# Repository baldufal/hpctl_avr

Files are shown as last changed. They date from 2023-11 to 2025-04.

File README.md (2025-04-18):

# HPCTL AVR
Software for Atmega48/88/168/328 controller of HPCTL heating and ventilation controller project.

We use it with Microchip Studio and Atmega168.

# Task
This mc is controlled by a [ESP32](https://github.com/baldufal/hpctl_arduino/tree/main) via I2C bus.
It drives 8 solid state relais (SSRs) and 8 mechanical relais and reports the state of 4 universal binary inputs.
3 of the SSRs are connected to a heater. They are driven with very slow PWM with a period of 10s.
The mechanical relais control one ventilator.
Another ventilator is controlled via PWM on one of the SSR outputs (SSR3/PD3).

# I2C Interface
The I2C interface exposes 6 8bit registers:
Register | Semantics | Allowed values (writing)
---|---|---
0 | Heater level | 0-30
1 | Vent IN | 0-255
2 | Vent OUT | 0-6
3 | SSRs | 0b000x0xxx
4 | Checksum | -
5 | Inputs | -

- The three most significant bits of register 3 are determined by heater level. They cannot be set manually, but their current values can be read from this register.
- Similarly for 4th bit (0b00001000) is controlled by the Vent OUT level (1kHz PWM).
- The checksum is the inverse of the 8bit sum of registers 0 to 3.
- The lower 4 bits of register 5 contain the actual input states.
- The upper 4 bits of register 5 contain the bitwise inverse of the input states.

# Board
We use the controller on a custom PCB. It additionally provides the corresponding ESP32 with 5V supply voltage and a debounced terminal for 4 buttons which are connected directly to the ESP32.

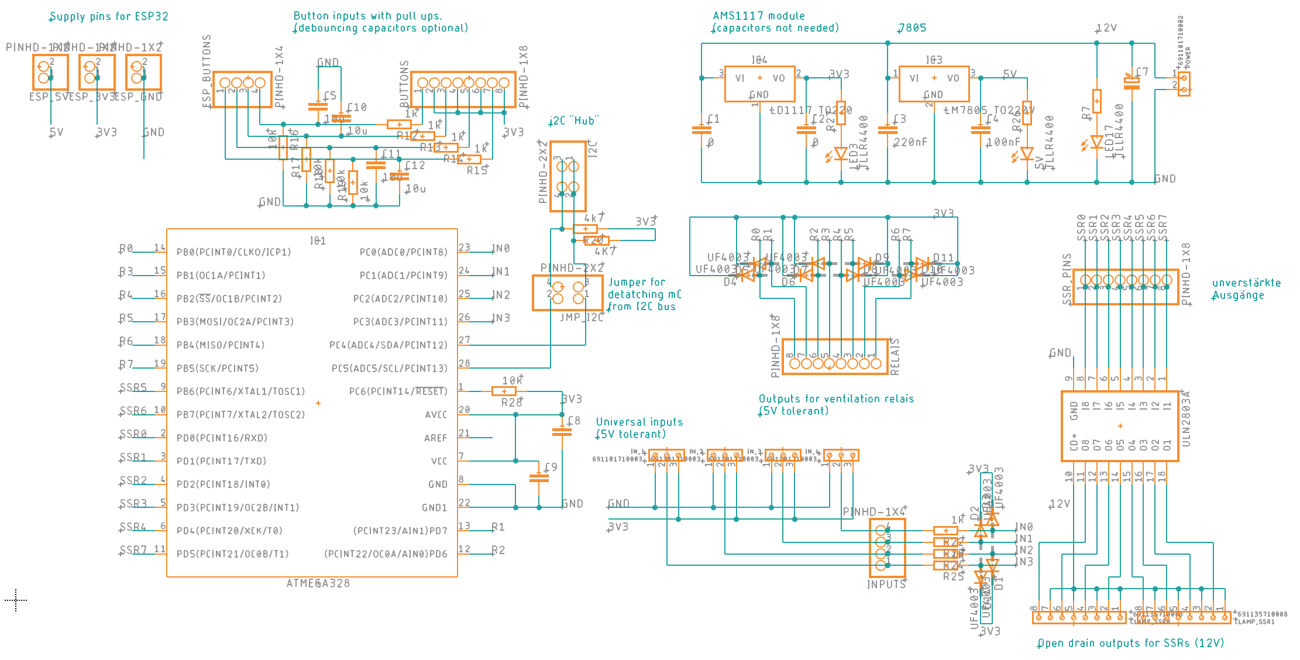
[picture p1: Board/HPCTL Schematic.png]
schematic


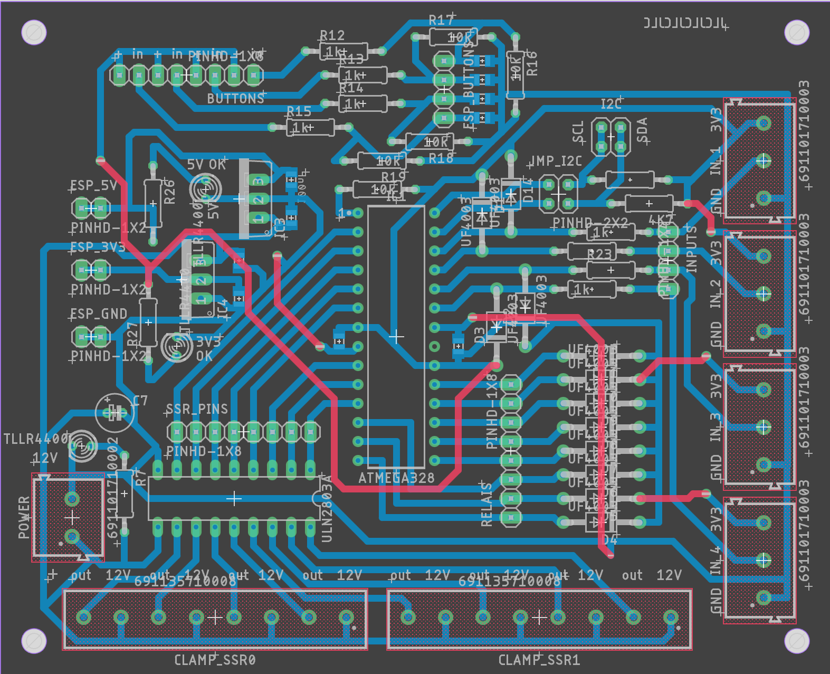
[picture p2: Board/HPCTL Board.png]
board

The layout file uses a wrong footprint for the mC.

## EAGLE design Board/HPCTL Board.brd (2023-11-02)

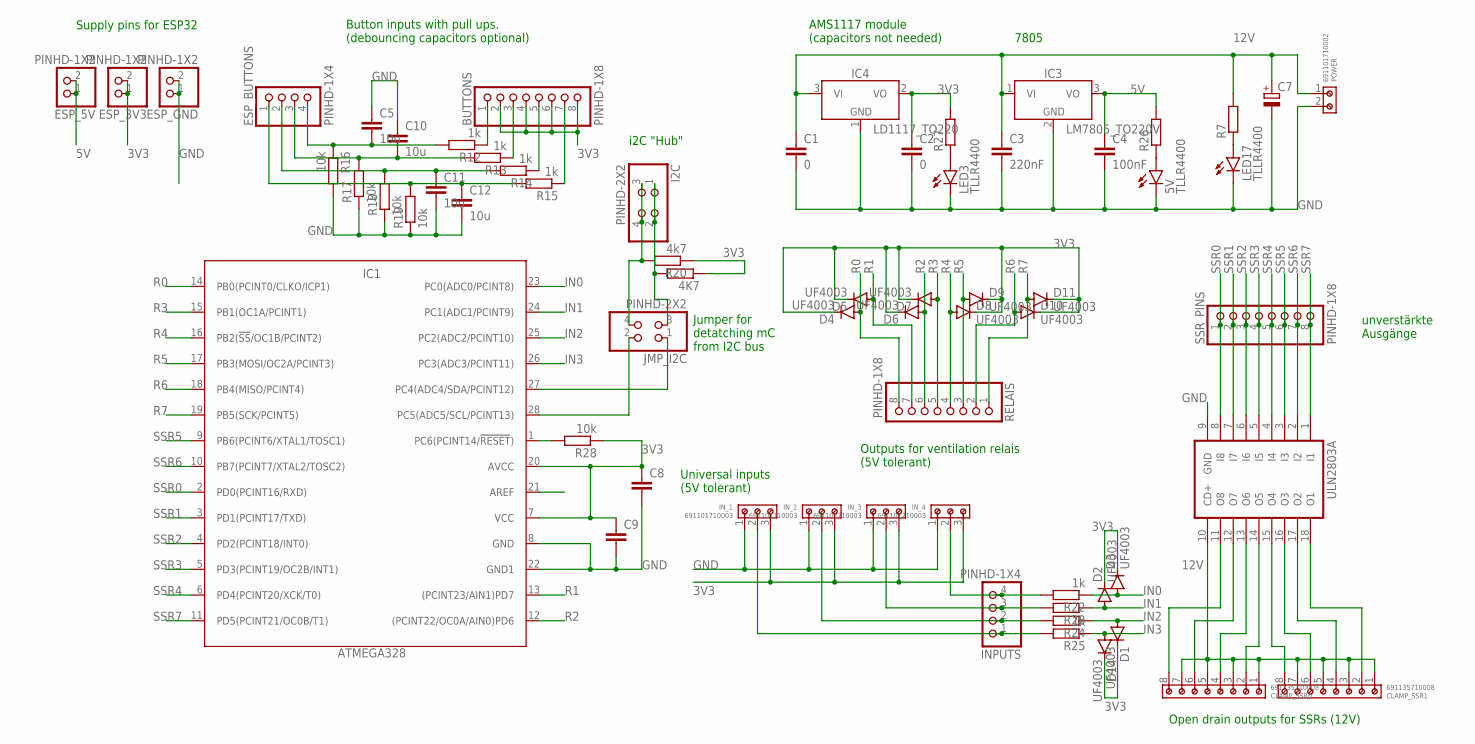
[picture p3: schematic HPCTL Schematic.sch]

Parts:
4K7: R-EU_0207/10; 0207/10
5V: TLLR4400; LED3MM
BUTTONS: PINHD-1X8; 1X08
C1, C2: 0; C0805K
C3: 220nF; C0805K
C4: 100nF; C0805K
C5, C10, C11, C12: 10u; C0805K
C7: CPOL-EUE2-5; E2-5
C8, C9: C-EUC0805K; C0805K
CLAMP_SSR0, CLAMP_SSR1: 691135710008
D1, D2, D3, D4, D5, D6, D7, D8, D9, D10, D11, D14: UF4003; DO41-10
ESP_3V3, ESP_5V: PINHD-1X2; 1X02
ESP_BUTTONS: PINHD-1X4; 1X04
ESP_GND: PINHD-1X2; 1X02
I2C: PINHD-2X2; 2X02
IC1: ATMEGA328; DIP1016W53P254L3467H457Q28B
IC3: LM7805_TO220V; TO220V
IC4: LD1117_TO220; TO220V
INPUTS: PINHD-1X4; 1X04
IN_1, IN_2, IN_3, IN_4: 691101710003
JMP_I2C: PINHD-2X2; 2X02
LED3, LED17: TLLR4400; LED3MM
POWER: 691101710002
R7, R23, R24, R26, R27: R-EU_0207/10; 0207/10
R12, R13, R14, R15, R22, R25: 1k; 0207/10
R16, R17, R18, R19, R28: 10k; 0207/10
R20: 4k7; 0207/10
RELAIS: PINHD-1X8; 1X08
SSR_PINS: PINHD-1X8; 1X08
ULN2803A: ULN2804A; DIL18

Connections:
3V3: 4K7.1, BUTTONS.2, BUTTONS.4, BUTTONS.6, BUTTONS.8, C2.1, C8.1, C9.1, D1.C, D2.C, D3.C, D4.C, D5.C, D6.C, D7.C, D8.C, D9.C, D10.C, D11.C, D14.C, ESP_3V3.1, ESP_3V3.2, IC1.7 (VCC), IC1.20 (AVCC), IC4.2 (VO), IN_1.3, IN_2.3, IN_3.3, IN_4.3, R20.1, R27.2, R28.1
5V: C4.1, ESP_5V.1, ESP_5V.2, IC3.3 (VO), R26.2
12V: C1.1, C3.1, C7.+, CLAMP_SSR0.1, CLAMP_SSR0.3, CLAMP_SSR0.5, CLAMP_SSR0.7, CLAMP_SSR1.1, CLAMP_SSR1.3, CLAMP_SSR1.5, CLAMP_SSR1.7, IC3.1 (VI), IC4.3 (VI), POWER.1, R7.2, ULN2803A.10 (CD+)
GND: 5V.K (C), C1.2, C2.2, C3.2, C4.2, C5.1, C7.-, C8.2, C9.2, C10.1, C11.2, C12.2, ESP_GND.1, ESP_GND.2, IC1.8 (GND), IC1.22 (GND1), IC3.2 (GND), IC4.1 (GND), IN_1.1, IN_2.1, IN_3.1, IN_4.1, LED3.K (C), LED17.K (C), POWER.2, R16.2, R17.1, R18.1, R19.1, ULN2803A.9 (GND)
IN0: D3.A, IC1.23 (PC0(ADC0/PCINT8)), R22.1
IN1: D2.A, IC1.24 (PC1(ADC1/PCINT9)), R23.1
IN2: D1.A, IC1.25 (PC2(ADC2/PCINT10)), R24.1
IN3: D14.A, IC1.26 (PC3(ADC3/PCINT11)), R25.1
unnamed: I2C.3, I2C.4, JMP_I2C.4, R20.2
unnamed: 4K7.2, I2C.1, I2C.2, JMP_I2C.3
unnamed: BUTTONS.7, R15.1
unnamed: BUTTONS.5, R14.1
unnamed: BUTTONS.3, R13.1
unnamed: BUTTONS.1, R12.1
unnamed: LED17.A, R7.1
unnamed: CLAMP_SSR0.8, ULN2803A.11 (O8)
unnamed: CLAMP_SSR0.6, ULN2803A.12 (O7)
unnamed: CLAMP_SSR0.4, ULN2803A.13 (O6)
unnamed: CLAMP_SSR0.2, ULN2803A.14 (O5)
unnamed: CLAMP_SSR1.8, ULN2803A.15 (O4)
unnamed: CLAMP_SSR1.6, ULN2803A.16 (O3)
unnamed: CLAMP_SSR1.4, ULN2803A.17 (O2)
unnamed: CLAMP_SSR1.2, ULN2803A.18 (O1)
unnamed: C5.2, ESP_BUTTONS.4, R12.2, R16.1
unnamed: C12.1, ESP_BUTTONS.1, R15.2, R19.2
unnamed: C11.1, ESP_BUTTONS.2, R14.2, R18.2
unnamed: INPUTS.4, IN_4.2, R22.2
unnamed: C10.2, ESP_BUTTONS.3, R13.2, R17.2
unnamed: INPUTS.3, IN_3.2, R23.2
unnamed: INPUTS.2, IN_2.2, R24.2
unnamed: INPUTS.1, IN_1.2, R25.2
unnamed: 5V.A, R26.1
unnamed: LED3.A, R27.1
unnamed: IC1.1 (PC6(PCINT14/!RESET!)), R28.2
R0: D4.A, IC1.14 (PB0(PCINT0/CLKO/ICP1)), RELAIS.8
R1: D5.A, IC1.13 ((PCINT23/AIN1)PD7), RELAIS.7
R2: D6.A, IC1.12 ((PCINT22/OC0A/AIN0)PD6), RELAIS.6
R3: D7.A, IC1.15 (PB1(OC1A/PCINT1)), RELAIS.5
R4: D8.A, IC1.16 (PB2(!SS!/OC1B/PCINT2)), RELAIS.4
R5: D9.A, IC1.17 (PB3(MOSI/OC2A/PCINT3)), RELAIS.3
R6: D10.A, IC1.18 (PB4(MISO/PCINT4)), RELAIS.2
R7: D11.A, IC1.19 (PB5(SCK/PCINT5)), RELAIS.1
SCL: IC1.28 (PC5(ADC5/SCL/PCINT13)), JMP_I2C.2
SDA: IC1.27 (PC4(ADC4/SDA/PCINT12)), JMP_I2C.1
SSR0: IC1.2 (PD0(PCINT16/RXD)), SSR_PINS.1, ULN2803A.8 (I8)
SSR1: IC1.3 (PD1(PCINT17/TXD)), SSR_PINS.2, ULN2803A.7 (I7)
SSR2: IC1.4 (PD2(PCINT18/INT0)), SSR_PINS.3, ULN2803A.6 (I6)
SSR3: IC1.5 (PD3(PCINT19/OC2B/INT1)), SSR_PINS.4, ULN2803A.5 (I5)
SSR4: IC1.6 (PD4(PCINT20/XCK/T0)), SSR_PINS.5, ULN2803A.4 (I4)
SSR5: IC1.9 (PB6(PCINT6/XTAL1/TOSC1)), SSR_PINS.6, ULN2803A.3 (I3)
SSR6: IC1.10 (PB7(PCINT7/XTAL2/TOSC2)), SSR_PINS.7, ULN2803A.2 (I2)
SSR7: IC1.11 (PD5(PCINT21/OC0B/T1)), SSR_PINS.8, ULN2803A.1 (I1)

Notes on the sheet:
Button inputs with pull ups. (debouncing capacitors optional)
7805
AMS1117 module (capacitors not needed)
Supply pins for ESP32
Jumper for detatching mC from I2C bus
i2C "Hub"
unverstärkte Ausgänge
Open drain outputs for SSRs (12V)
Outputs for ventilation relais (5V tolerant)
Universal inputs (5V tolerant)

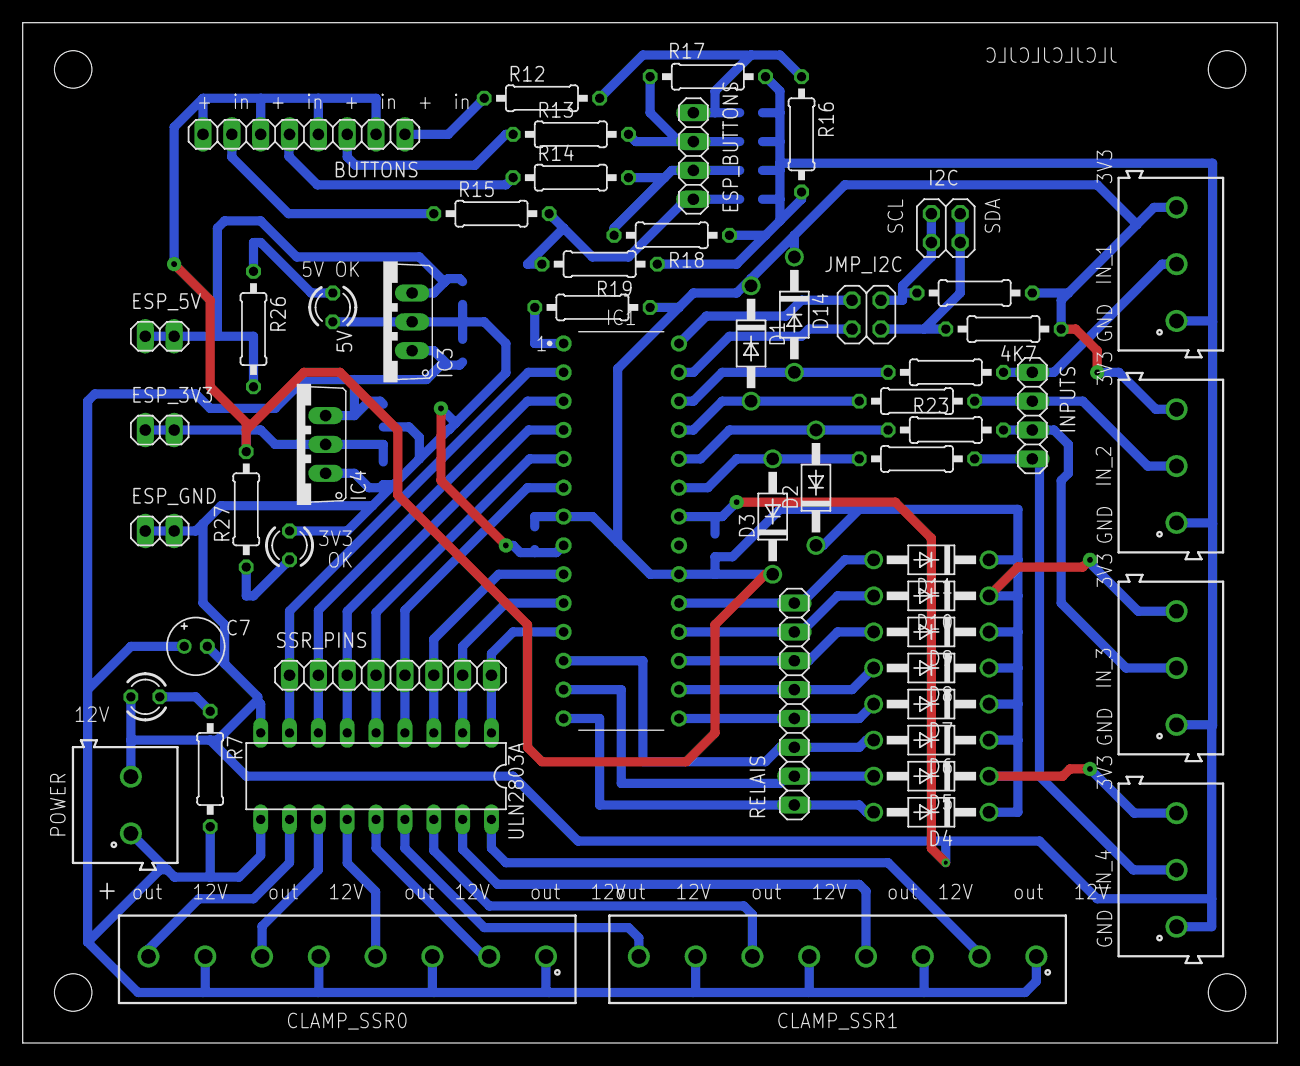
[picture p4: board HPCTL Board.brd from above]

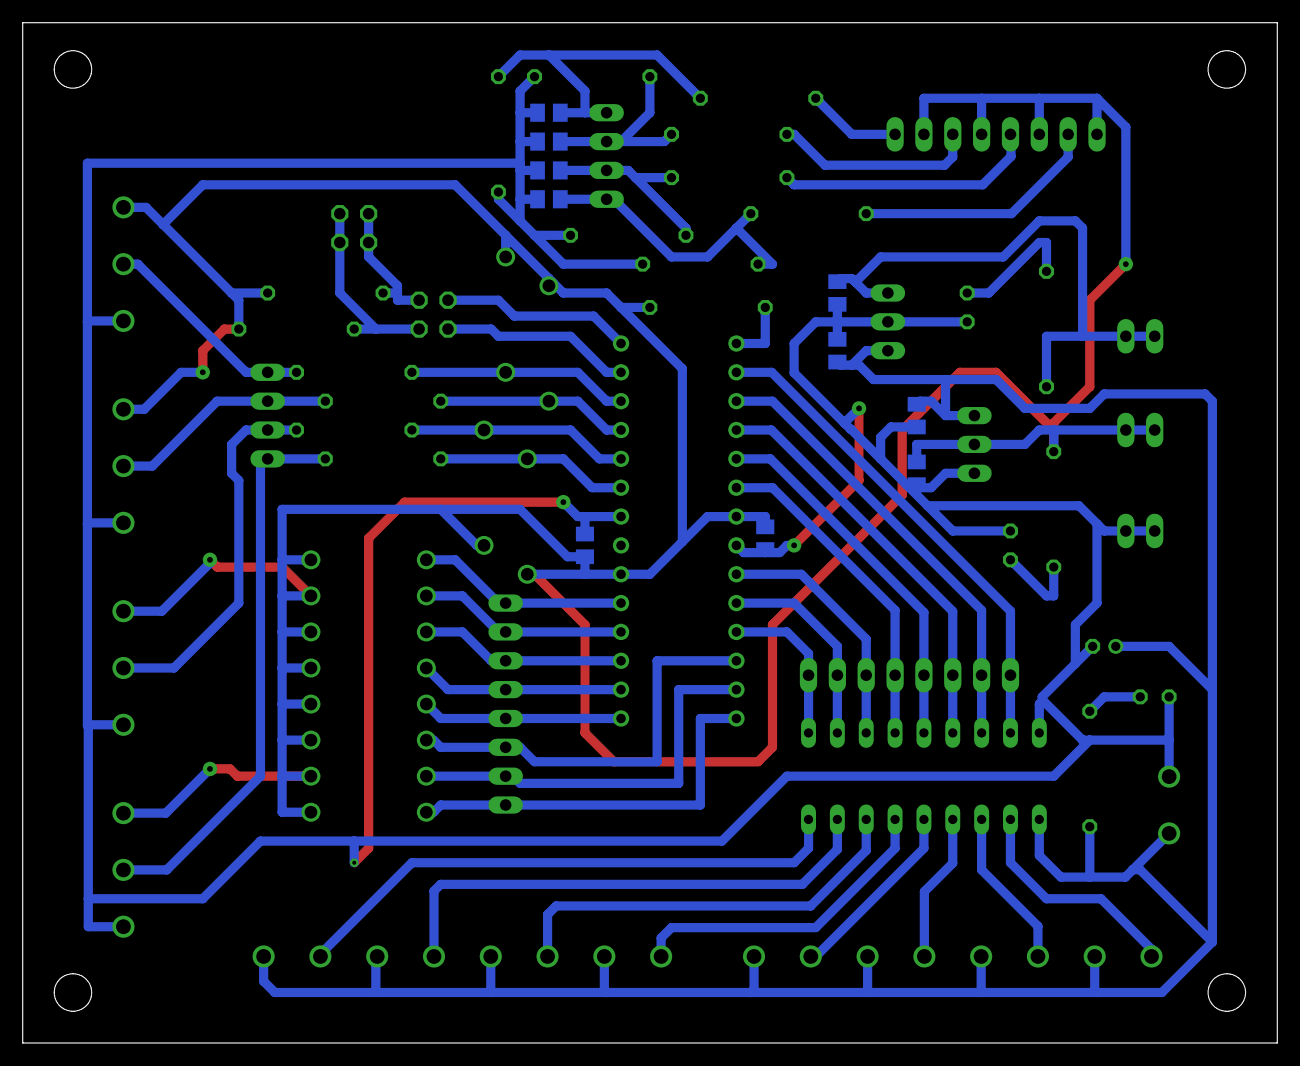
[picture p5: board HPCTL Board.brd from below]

Board: 2 copper layers, 110.5 x 89.8 mm, 65 parts (10 on the bottom side), 52 nets.

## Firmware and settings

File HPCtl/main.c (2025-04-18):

/*
* HPCtl.c
*
* Created: 05.10.2023 19:40:37
* For Atmega168
* Author : falkb
*/

#ifndef F_CPU
# define F_CPU 8000000UL
#endif

#include <avr/io.h>
#include <avr/interrupt.h>
#include <avr/wdt.h>
#include <util/delay.h>
#include "twislave.h"
#include "relay.h"

#define PWM_TICK_FREQUENCY_HZ 1
#define PWM_PERIOD_SECONDS 10
// The number of heater levels, defined by the PWM cycle.
#define NUM_HEATER_LEVELS (PWM_TICK_FREQUENCY_HZ * PWM_PERIOD_SECONDS * 3 + 1)

// A tick-counter driven by a timer.
// This counts seconds modulo some number.
volatile uint8_t timer_ticks;

// Initializes outputs.
static void io_init() {
	// No pull ups necessary because of external pull ups.
	// We use pull ups anyway to make debugging without external pull ups easier.
	
	// Outputs:
	// PD0..PD2, PD4:		General purpose SSRs
	// PD3:					Ventilation PWM
	// PD5, PB6, PB7:		Heater SSRs
	// PD6, PD7, PB0..PB5:	Relais
	
	// Inputs:
	// PC0..PC3:			General purpose Inputs
	// PC4, PC5:			I2C
	
	// Vent pins high = vent off
	PORTB = 0b00111111;
	DDRB = 0xFF;
	
	// PC0 to PC5 as inputs with pull ups enabled
	PORTC = 0xFF;
	DDRC = 0x00;
	
	// Vent pins high = vent off
	PORTD = 0b11000000;
	DDRD = 0xFF;
	
}

static void init_heater_timer() {
	// See http://www.8bit-era.cz/arduino-timer-interrupts-calculator.html
	// Or https://www.arduinoslovakia.eu/application/timer-calculator

	// ! Make sure this fits with PWM_TICK_FREQUENCY_HZ !

	TCCR1A = 0; // set entire TCCR1A register to 0
	TCCR1B = 0; // same for TCCR1B
	TCNT1 = 0; // initialize counter value to 0
	// set compare match register for 1 Hz increments
	OCR1A = 31249; // = 8000000 / (256 * 1) - 1 (must be <65536)
	// turn on CTC mode
	TCCR1B |= (1 << WGM12);
	// Set CS12, CS11 and CS10 bits for 256 prescaler
	TCCR1B |= (1 << CS12);
	// enable timer compare interrupt
	TIMSK1 |= (1 << OCIE1A); // Atmega8: TIMSK |= (1 << OCIE1A);
}

void init_vent_pwm_timer() {
	// Set initial duty cycle to 0/255
	OCR2B = 0;
	
	// Fast PWM Mode (WGM22:0 = 3), non-inverting mode on OC2B
	TCCR2A = (1 << COM2B1) | (1 << WGM21) | (1 << WGM20);
	
	// f_pwm = f_clk / (Prescaler * 256)
	// Prescaler = 32 => 980Hz
	TCCR2B = (1 << CS21) | (1 << CS20);
}


// Reads input pins PC0..PC3
static void readout() {
	// Read PC0..PC3
	uint8_t values = PINC & 0x0F;
	
	// Compute shifted complement
	uint8_t complement = ~values;
	complement = complement << 4;

	// Write to I2C buffer
	i2cdata[5] = complement | values;
}

static void compute_checksum(){
	cli();
	
	uint8_t sum = 0;
	sum += i2cdata[0];
	sum += i2cdata[1];
	sum += i2cdata[2];
	sum += i2cdata[3];
	i2cdata[4] = ~sum;
	
	sei();
}

static void set_heater(uint8_t level, uint8_t pwm_counter){
	if (level > 20) {
		PORTB |= (1<<PORTB6);
		PORTB |= (1<<PORTB7);
		uint8_t remainder = level - 20;
		if (remainder > pwm_counter) {
			PORTD |= (1<<PORTD5);
			} else {
			PORTD &= ~(1<<PORTD5);
		}
	}
	else {
		if (level > 10) {
			PORTB |= (1<<PORTB6);
			PORTD &= ~(1<<PORTD5);
			uint8_t remainder = level - 10;
			if (remainder > pwm_counter) {
				PORTB |= (1<<PORTB7);
				} else {
				PORTB &= ~(1<<PORTB7);
			}
		}
		else {
			PORTD &= ~(1<<PORTD5);
			PORTB &= ~(1<<PORTB7);
			if (level > pwm_counter) {
				PORTB |= (1<<PORTB6);
				} else {
				PORTB &= ~(1<<PORTB6);
			}
		}
	}

	// Expose SSR state to i2c.
	cli();
	i2cdata[3] &= 0b00011111;
	if(PORTB & (1<<PORTB6))
	i2cdata[3] |= (1<<5);
	if(PORTB & (1<<PORTB7))
	i2cdata[3] |= (1<<6);
	if(PORTD & (1<<PORTD5))
	i2cdata[3] |= (1<<7);
	sei();
}

static void set_ssrs(uint8_t value){
	// Mask out unaffected bits.
	uint8_t mask_reg_d = 0b00011111;
	value &= mask_reg_d;
	
	PORTD = (PORTD & ~mask_reg_d) | value;
}

static void set_air_out(uint8_t	value){
	OCR2B = value;
}

ISR(TIMER1_COMPA_vect) // every 1s
{
	timer_ticks = (timer_ticks + 1) % (PWM_PERIOD_SECONDS * PWM_TICK_FREQUENCY_HZ);
}


int main(void)
{
	io_init();
	// Enable watchdog to restart if we didn't reset it for 2 seconds.
	wdt_enable(WDTO_2S);
	// Enable I2C.
	init_twi_slave(I2C_SLAVE_ADDRESS);
	// Read input values
	readout();
	// Init 1Hz timer for the 3 heater SSRs
	init_heater_timer();
	// Init timer2 for ventilation PWM
	init_vent_pwm_timer();
	// Enable Interrupts.
	sei();
	
	while (1)
	{
		// Reset watchdog timer.
		wdt_reset();
		
		readout();
		
		compute_checksum();
		
		set_heater(i2cdata[0], timer_ticks);
		
		set_air_in(i2cdata[1]);
		set_air_out(i2cdata[2]);
		
		set_ssrs(i2cdata[3]);
	}
}

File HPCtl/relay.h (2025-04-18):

//
// Created by falk on 06/10/23.
//
// We have eight relays. The first four deal with air intake, the last four with air out.
// All relays are in their default state if the corresponding pins are HIGH.
// Relays are connected to PORTB and PORTD.
//
// ==============================
// AIR INTAKE
// ==============================
//
// Relays 1 and 3 have power inputs for air intake.
// Relay 1:
// - Not connected (default)
// - 100V (active)
// Relay 3:
// - 190V (default)
// - 230V (active)
//
// Relay 2 sits above that to multiplex. It has relay 1 selected by default.
// Relay 3 demuxes the output of relay 2 to the two fan modes:
// - Intake air fan mode 1 (default)
// - Intake air fan mode 2 (active)
//
// We thus have six air intake modes, plus off:
// - off: all relays in default position
// - mode 1: 100V + fan mode 1
// - mode 2: 100V + fan mode 2
// - mode 3: 190V + fan mode 1
// - mode 4: 230V + fan mode 1
// - mode 5: 190V + fan mode 2
// - mode 6: 230V + fan mode 2
//
// Additionally, there is one connection between the fan-controlling MCU and the heater-controlling MCU, which is
// hardwired to relay 1, with a pullup.
// This connection is used as a safety feature: Only if the pin is LOW will the heating run.
// This means that, even if the "path" via relay 1 is unused, we still need to actively drive it LOW to indicate that
// the fan is running.
//
// ==============================
// AIR OUT
// ==============================
//
// Relays 5,6, and 8 have power inputs. All arrays are arranged like a tree again:
// Relay 5:
// - Not connected (default)
// - 80 V (active)
// Relay 7:
// - 120V (default)
// - 150V (active)
// Relay 8:
// - [output of relay 6] (default)
// - 230V (active)
// Relay 6 multiplexes between relays 5 and 7.
//
// We thus end up with 4 air-out modes, plus off.

#ifndef FAN_CONTROL_RELAY_H
#define FAN_CONTROL_RELAY_H

#include <avr/io.h>

// Our relays are HIGH by default, i.e., all of this is actually inverted.
#define RELAY_0 (1 << PORTB0)
#define RELAY_1 (1 << PORTD7) // PORT _D_
#define RELAY_2 (1 << PORTD6) // PORT _D_
#define RELAY_3 (1 << PORTB1)
#define RELAY_4 (1 << PORTB2)
#define RELAY_5 (1 << PORTB3)
#define RELAY_6 (1 << PORTB4)
#define RELAY_7 (1 << PORTB5)


#define NUM_AIR_IN_MODES 7
#define NUM_AIR_OUT_MODES 5

#define MASK_IN_B 0b00000011
#define MASK_IN_D 0b11000000
#define MASK_OUT_B 0b00111100


static void set_air_in(uint8_t level) {
	uint8_t reg_b = MASK_IN_B;
	uint8_t reg_d = MASK_IN_D;
	
	switch (level) {
		case 0:
		//return 0;
		break;
		case 1:
		//return RELAY_0;
		reg_b &= ~(RELAY_0);
		break;
		case 2:
		//return RELAY_0 | RELAY_3;
		reg_b &= ~(RELAY_0 | RELAY_3);
		break;
		case 3:
		//return RELAY_0 | RELAY_1;
		reg_b &= ~RELAY_0;
		reg_d &= ~RELAY_1;
		break;
		case 4:
		//return RELAY_0 | RELAY_2 | RELAY_1;
		reg_b &= ~RELAY_0;
		reg_d &= ~(RELAY_1 | RELAY_2);
		break;
		case 5:
		//return RELAY_0 | RELAY_1 | RELAY_3;
		reg_b &= ~(RELAY_0 | RELAY_3);
		reg_d &= ~RELAY_1;
		break;
		case 6:
		//return RELAY_0 | RELAY_1 | RELAY_2 | RELAY_3;
		reg_b &= ~(RELAY_0 | RELAY_3);
		reg_d &= ~(RELAY_1 | RELAY_2);
		break;
	}
	
	// Set registers without transient states and without affecting other bits
	reg_b = reg_b | (PORTB & ~MASK_IN_B);
	PORTB = reg_b;
	reg_d = reg_d | (PORTD & ~MASK_IN_D);
	PORTD = reg_d;
}

// This is not needed anymore because the ventilator is controlled via PWM on SSR3.
/*
static void set_air_out(uint8_t level) {
	uint8_t reg_b = MASK_OUT_B;
	
	switch (level) {
		case 0:
		//return 0;
		break;
		case 1:
		//return RELAY_4;
		reg_b &= ~RELAY_4;
		break;
		case 2:
		//return RELAY_5;
		reg_b &= ~RELAY_5;
		break;
		case 3:
		//return RELAY_5 | RELAY_6;
		reg_b &= ~(RELAY_5 | RELAY_6);
		break;
		case 4:
		//return RELAY_7;
		reg_b &= ~RELAY_7;
		break;
	}
	
	// Set register without transient states and without affecting other bits
	reg_b = reg_b | (PORTB & ~MASK_OUT_B);
	PORTB = reg_b;
}
*/


#endif //FAN_CONTROL_RELAY_H

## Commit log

2023-11-02 Add board files
    [HPCTL Board.brd, HPCTL Schematic.sch]
2025-04-18 Change vent_in to PWM
2025-04-18 Update README.md
    Adapt to PWM control of Vent IN

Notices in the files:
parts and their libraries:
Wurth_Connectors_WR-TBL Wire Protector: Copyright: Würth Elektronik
